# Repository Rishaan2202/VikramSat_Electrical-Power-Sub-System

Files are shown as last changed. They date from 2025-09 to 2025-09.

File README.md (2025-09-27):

# VikramSat.v0 EPS Journal!!!
<br>
<h3>Yooooo!!! It's me, Rishaan Sharma, a 14 year old Indian boy making a satellite with 4 of my teammates.
<br>
The Satellite is named as 'VikramSat'. It's a 2U CubeSat and yeah it's quite a cool project!
<br>
<br>
I have been assigned the duty to make a fully functional Electrical Power Sub-System (EPS) for the CubeSat.
<br>
<br>
So, I'm writing this journal which notifies about the progress regularly.
<br>
I hope you all will find this quite interesting. For more details do view JOURNAL.md in this repository containing the journal.</h3>
<br>
<br>
<h3>So, you might have gone throught JOURNAL.md, pretty interesting, right? Well, here is the Schematic of the EPS:-</h3>

<br>
<br>
<h3>Boom!!! It's Vampire Theme. I hope you like it. Here comes the PCB:-</h3>

<br>
<br>
<h3>Well, take a look at the 'Power Monster':-</h3>


<br>
<br>
<h3>You wanna see the BOM:-</h3>

<br>
<br>
<h3>Here's the Screenshot of the Cart for both LCSC and JLCPCB:-</h3>
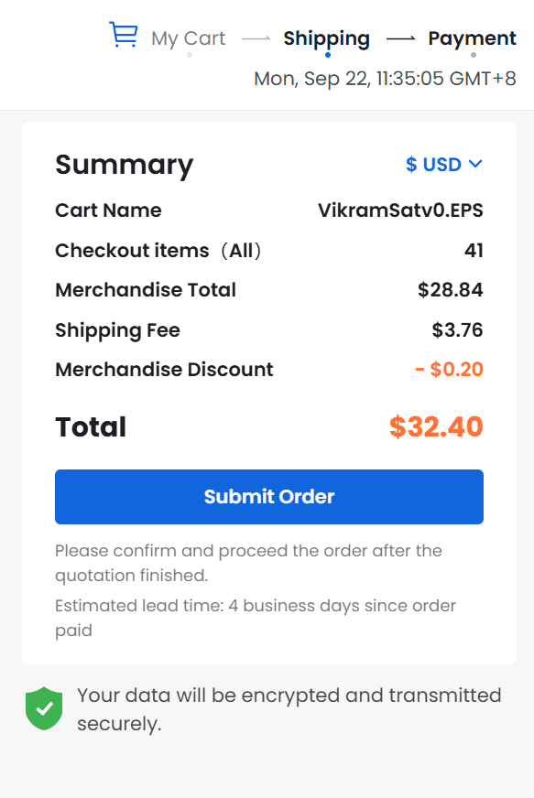
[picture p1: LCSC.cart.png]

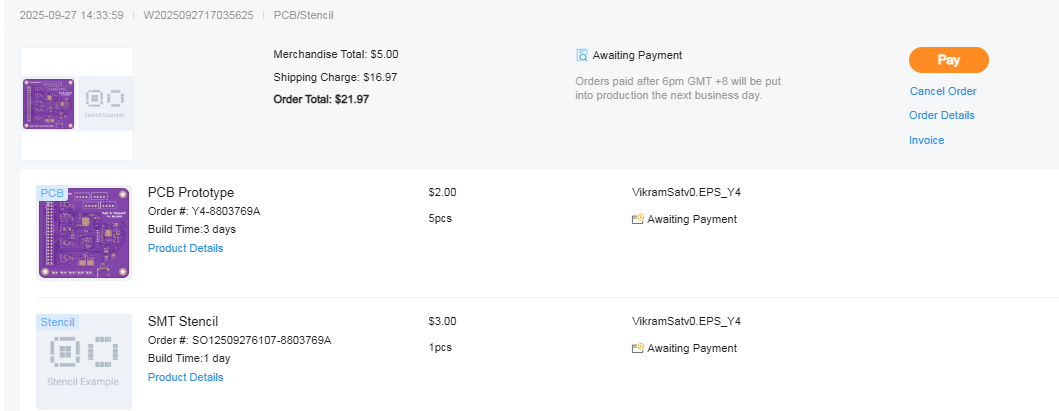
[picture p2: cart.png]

<br>
<h3>I hope you like them, well I couldn't do this better than that, cause I'm just a beginner!!!</h3>

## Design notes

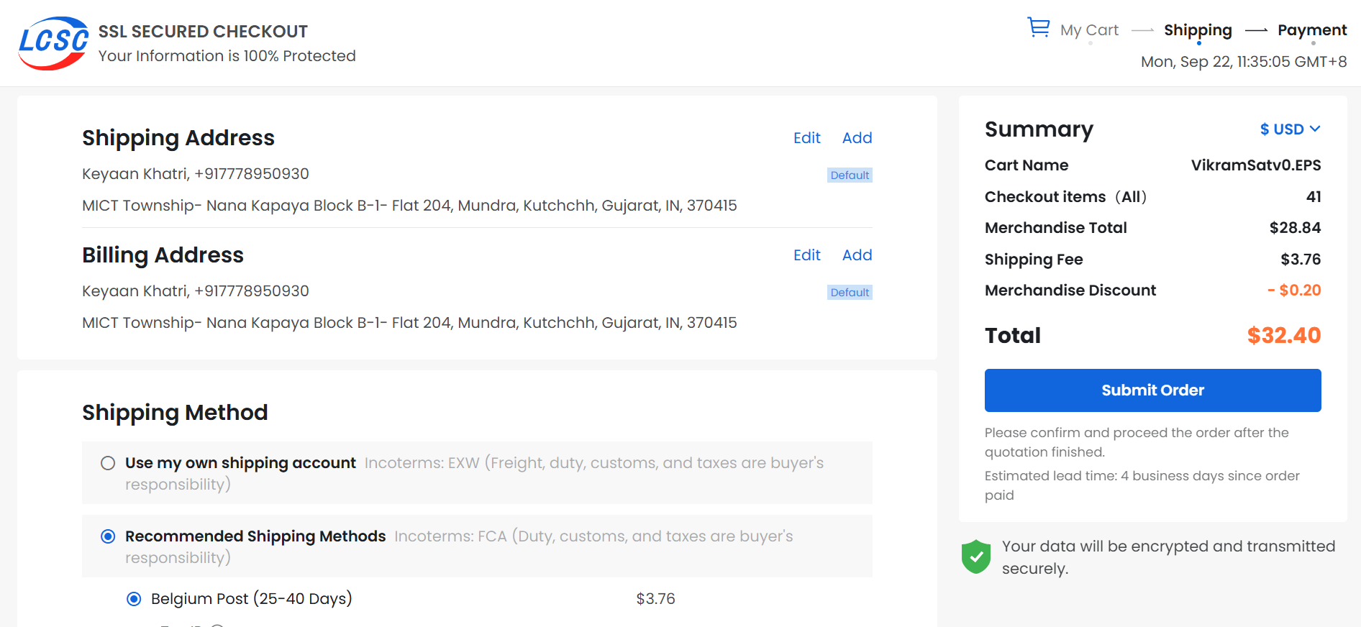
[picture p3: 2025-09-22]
Screenshot 2025-09-22 090605.png

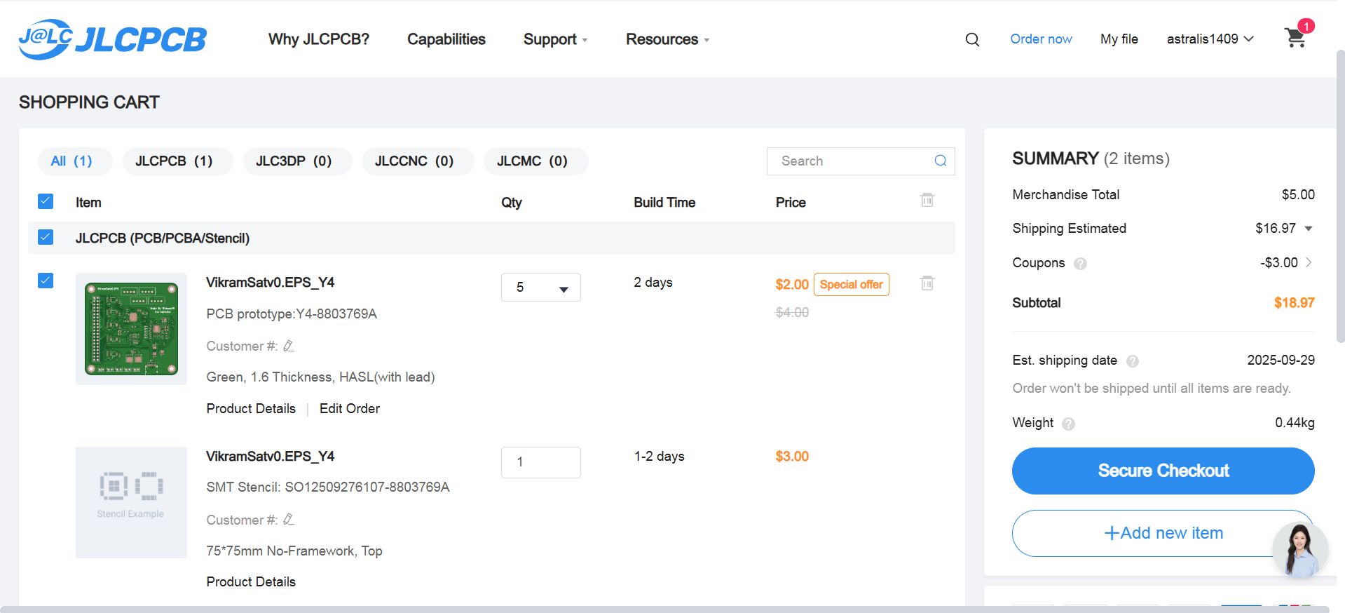
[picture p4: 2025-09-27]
Screenshot 2025-09-27 141404.png

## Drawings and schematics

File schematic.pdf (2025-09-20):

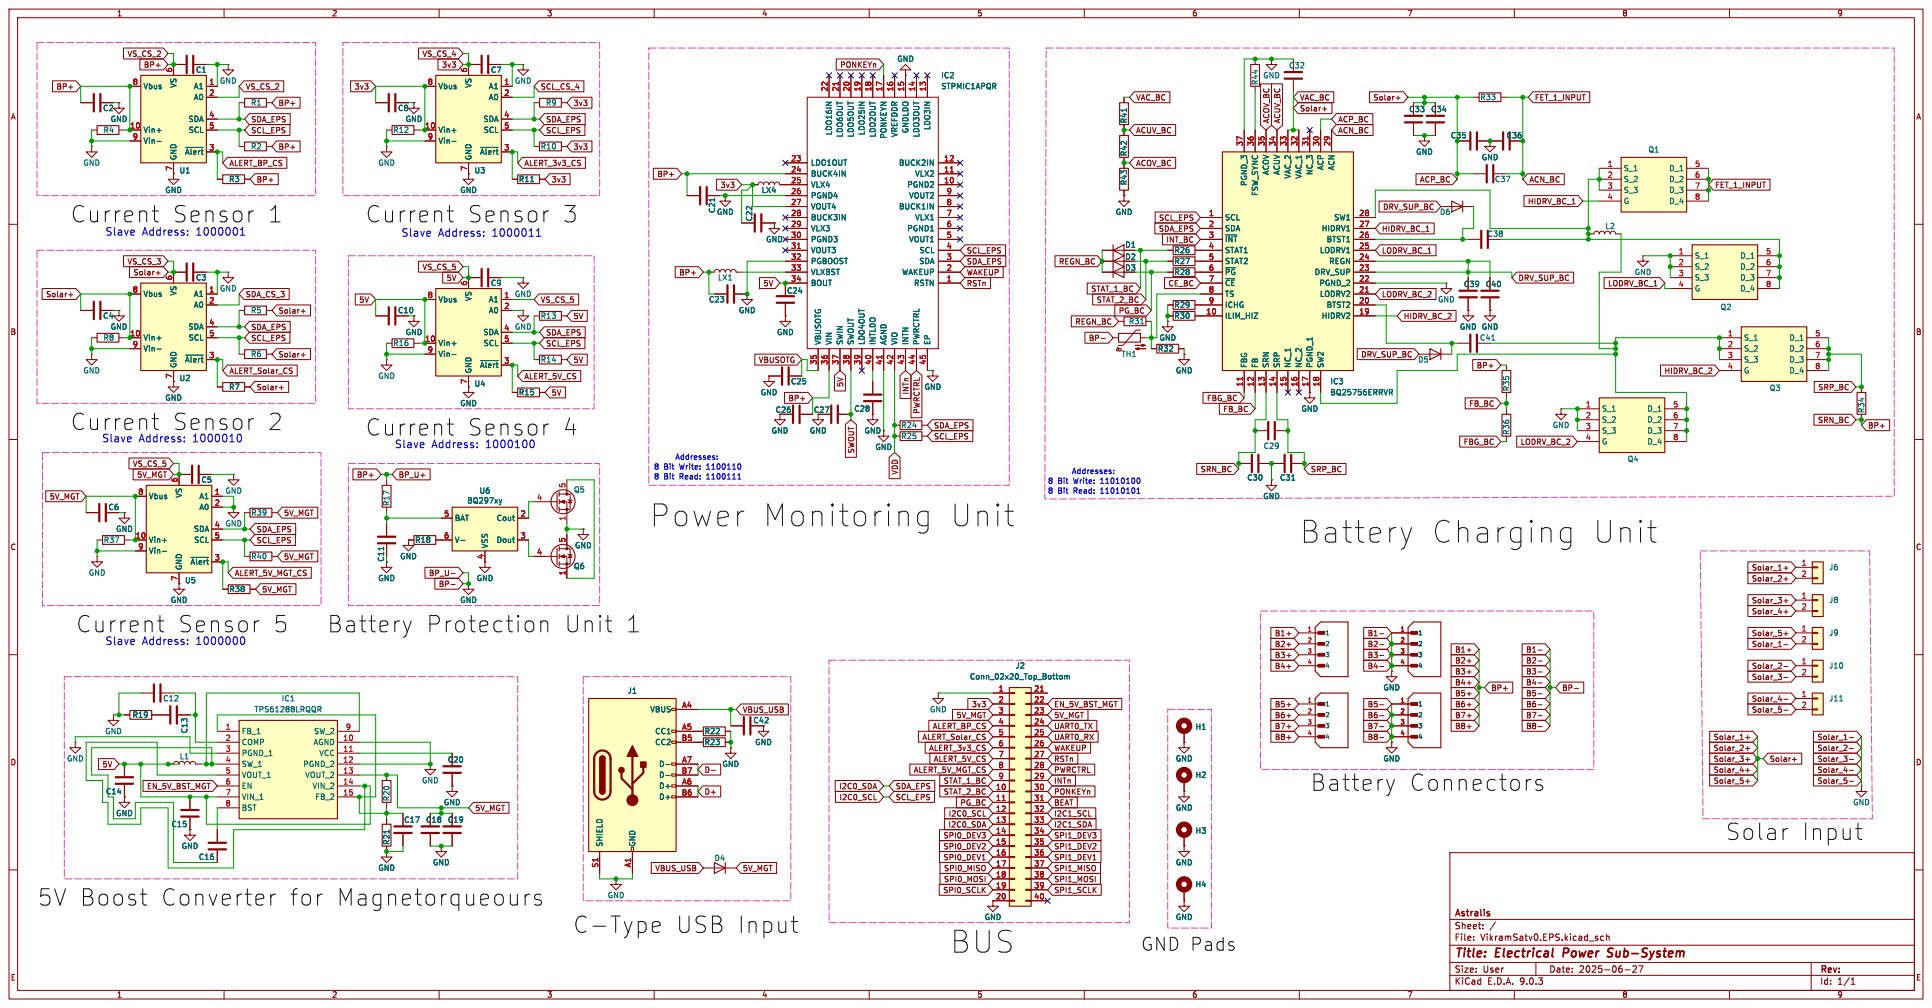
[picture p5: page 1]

7 A1 1 A0 2 SDA 4 SCL 5 ~{Alert}3 C1 GND

7 A1 1 A0 2 SDA 4 SCL 5 ~{Alert}3 U1 GND

7 A1 1 A0 2 SDA 4 SCL 5 ~{Alert}3 GND

7 A1 1 A0 2 SDA 4 SCL 5 ~{Alert}3 U4 C9 Vbus 8 Vin+ 10 Vin- 9 VS

7 A1 1 A0 2 SDA 4 SCL 5 ~{Alert}3 C9 U3 Vbus 8 Vin+ 10 Vin- 9 VS

7 A1 1 A0 2 SDA 4 SCL 5 ~{Alert}3 R7 GND

7 A1 1 A0 2 SDA 4 SCL 5 ~{Alert}3 U2 R39 GND

8 Q4 GND R36 R35 C41 D5 GND GND GND

7 A1 1 A0 2 SDA 4 SCL 5 ~{Alert}3 U5 GND

4 Cout 2 Dout 3 R18 U5 Vbus 8 Vin+ 10 Vin- 9 VS

5 1 GND GND GND GND C11 GND

5V Boost Converter for Magnetorqueours

Id: 1/1 Title: Electrical Power Sub-System

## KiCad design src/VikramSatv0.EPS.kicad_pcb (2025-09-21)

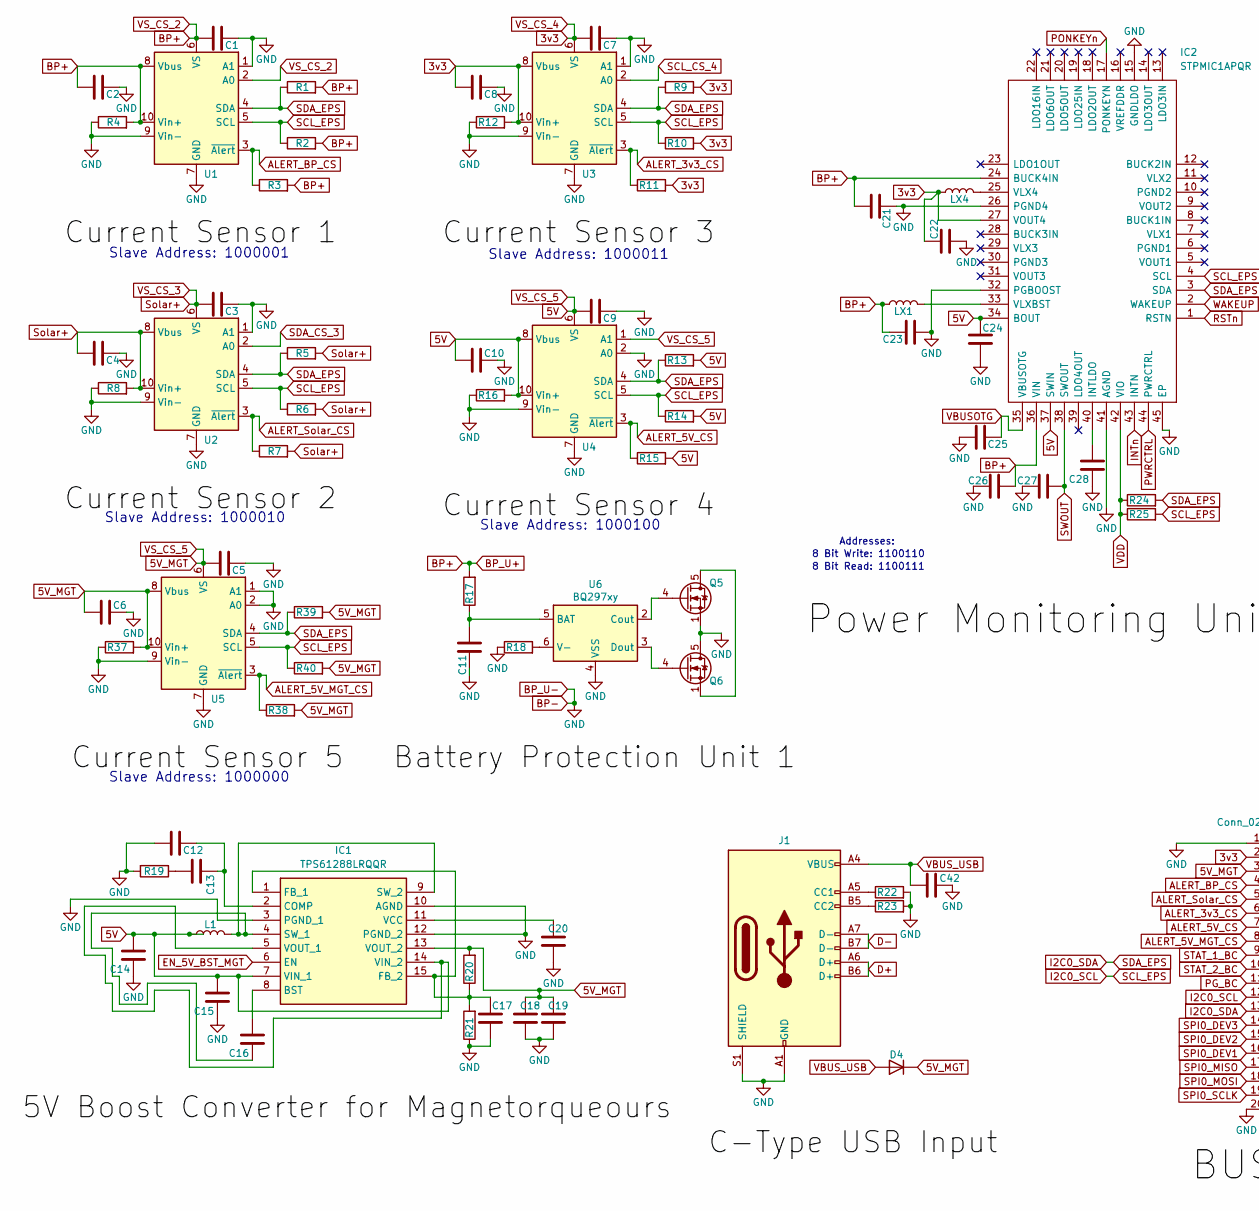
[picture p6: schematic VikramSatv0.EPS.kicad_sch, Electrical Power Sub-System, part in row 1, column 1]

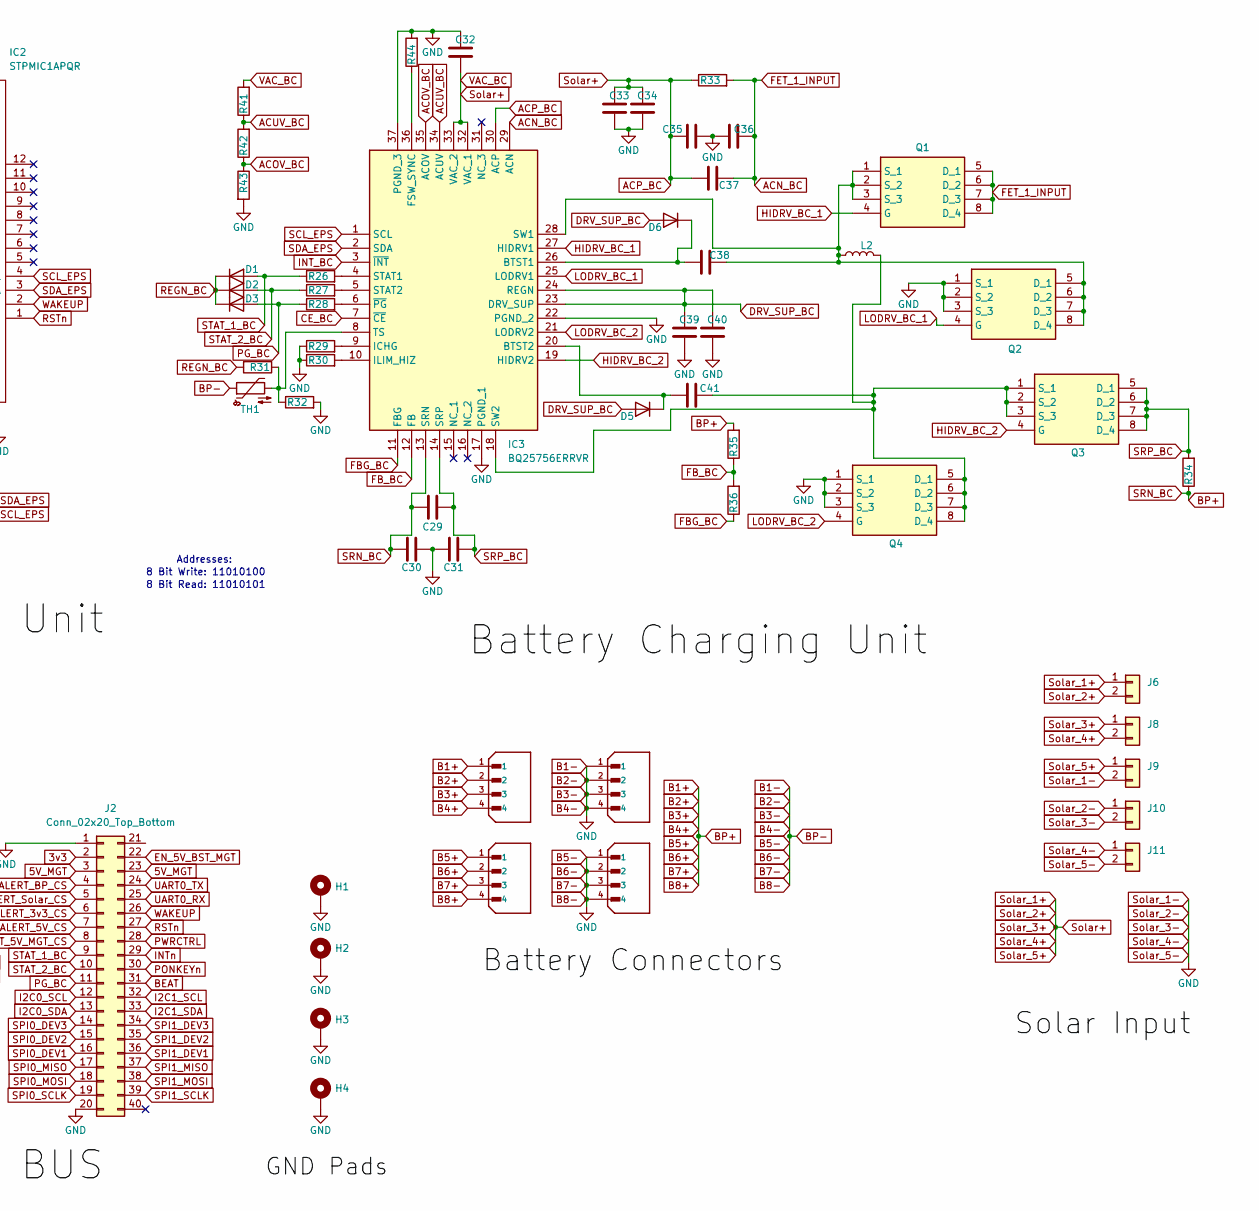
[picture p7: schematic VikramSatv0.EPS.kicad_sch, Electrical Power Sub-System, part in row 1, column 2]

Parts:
C1, C2, C3, C4, C5, C6, C7, C8, C9, C10, C11, C12, C15, C16, C17, C20, C29, C30, C31, C38, C41: 0.1uF; C_0402_1005Metric
C13: 1nF; C_0402_1005Metric
C14, C21, C22, C23, C24: 10uF; C_0805_2012Metric
C18, C19: 22uF; C_0402_1005Metric
C25, C26, C28, C39, C40: 4.7uF; C_0402_1005Metric
C27: 220uF; C_1206_3216Metric
C32, C42: 1uF; C_0402_1005Metric
C33, C34: 100uF; C_0805_2012Metric
C35, C36, C37: 470nF; C_0402_1005Metric
D1, D2, D3, D4, D5, D6: 1N4148WT; D_SOD-523
H1, H2, H3, H4: MountingHole_Pad; MountingHole_3mm_Pad_Via
IC1: TPS61288LRQQR; TPS61288; Mouser Part Number 595-TPS61288LRQQR
IC2: STPMIC1APQR; STPMIC1A; Mouser Part Number 511-STPMIC1APQR
IC3: BQ25756ERRVR; QFN50P500X600X100-37N-D; Mouser Part Number 595-BQ25756ERRVR
J1: USB_C_Receptacle_USB2.0_14P; USB_C_Receptacle_HRO_TYPE-C-31-M-12
J2: Conn_02x20_Top_Bottom; PinHeader_2x20_P2.54mm_Vertical
J3, J4, J5, J7: B4B-XH-A; JST_B4B-XH-A
J6, J8, J9, J10, J11: Conn_01x02; PinHeader_2x01_P2.54mm_Vertical
L1: 2.2uH; L_0402_1005Metric
L2: 10uH; L_0201_0603Metric
LX1, LX4: 1uH; L_0402_1005Metric
Q1, Q2, Q3, Q4: Mosfet 20A, 30V; Mouser Part Number 78-SISA14DN-T1-GE3
Q5, Q6: CSD16401Q5; TDSON-8-1
R1, R2, R5, R6, R9, R10, R13, R14, R24, R25, R39, R40: 4.7kΩ; R_0402_1005Metric
R3, R7, R11, R15, R22, R23, R26, R27, R28, R38: 10kΩ; R_0402_1005Metric
R4, R8, R12, R16, R37: 4mΩ; R_0402_1005Metric
R17: 330Ω; R_0402_1005Metric
R18: 2.2kΩ; R_0402_1005Metric
R19: 36.5kΩ; R_0402_1005Metric
R20: 105kΩ; R_0402_1005Metric
R21: 14.3kΩ; R_0402_1005Metric
R29: 4.22kΩ; R_0402_1005Metric
R30: 19.1kΩ; R_0402_1005Metric
R31: 5.23kΩ; R_0402_1005Metric
R32: 30.1kΩ; R_0402_1005Metric
R33: 1mΩ; R_0402_1005Metric
R34: 5mΩ; R_0402_1005Metric
R35: 174kΩ; R_0402_1005Metric
R36: 100kΩ; R_0402_1005Metric
R41: 357kΩ; R_0402_1005Metric
R42: 75kΩ; R_0402_1005Metric
R43: 22.6kΩ; R_0402_1005Metric
R44: 133kΩ; R_0402_1005Metric
TH1: 10kΩ NTC; R_0402_1005Metric
U1, U2, U3, U4, U5: INA226; VSSOP-10_3x3mm_P0.5mm
U6: BQ297xy; WSON-6_1.5x1.5mm_P0.5mm

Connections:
3v3: C7.2, C8.2, C22.1, IC2.27 (VOUT4), J2.2, LX4.1, R9.2, R10.2, R11.2, R12.2, U3.6 (VS), U3.8 (Vbus), U3.10 (Vin+)
5V: C5.2, C6.2, C9.2, C10.2, C14.2, C15.2, C18.2, C19.2, C24.1, D4.1 (K), IC1.5 (VOUT_1), IC1.7 (VIN_1), IC1.13 (VOUT_2), IC1.14 (VIN_2), IC2.34 (BOUT), IC2.37 (SWIN), J2.3, J2.23, L1.1, R13.2, R14.2, R15.2, R16.2, R20.2, R37.2, R38.2, R39.2, R40.2, U4.1 (A1), U4.6 (VS), U4.8 (Vbus), U4.10 (Vin+), U5.6 (VS), U5.8 (Vbus), U5.10 (Vin+)
ACN_BC: C36.2, C37.1, IC3.29 (ACN), Q1.5 (D_1), Q1.6 (D_2), Q1.7 (D_3), Q1.8 (D_4), R33.2
ACOV_BC: IC3.35 (ACOV), R42.1, R43.1
ACP_BC: C3.2, C4.2, C32.1, C33.2, C34.2, C35.1, C37.2, IC3.30 (ACP), IC3.32 (VAC_1), IC3.33 (VAC_2), J6.1, J6.2, J8.1, J8.2, J9.1, R5.2, R6.2, R7.2, R8.2, R33.1, R41.2, U2.6 (VS), U2.8 (Vbus), U2.10 (Vin+)
ACUV_BC: IC3.34 (ACUV), R41.1, R42.2
ALERT_3v3_CS: J2.6, R11.1, U3.3 (~Alert)
ALERT_5V_CS: J2.7, R15.1, U4.3 (~Alert)
ALERT_5V_MGT_CS: J2.8, R38.1, U5.3 (~Alert)
ALERT_BP_CS: J2.4, R3.1, U1.3 (~Alert)
ALERT_Solar_CS: J2.5, R7.1, U2.3 (~Alert)
B1+: C1.2, C2.2, C21.2, C23.1, C26.2, C29.1, C30.1, IC2.24 (BUCK4IN), IC2.36 (VIN), IC3.13 (SRN), J4.1, J4.2, J4.3, J4.4, J7.1, J7.2, J7.3, J7.4, LX1.1, R1.2, R2.2, R3.2, R4.2, R17.2, R34.1, R35.2, U1.2 (A0), U1.6 (VS), U1.8 (Vbus), U1.10 (Vin+)
B1-: C1.1, C2.1, C3.1, C4.1, C5.1, C6.1, C7.1, C8.1, C9.1, C10.1, C11.1, C12.2, C14.1, C15.1, C17.1, C18.1, C19.1, C20.1, C21.1, C22.2, C23.2, C24.2, C25.1, C26.1, C27.1, C28.1, C30.2, C31.1, C32.2, C33.1, C34.1, C35.2, C36.1, C39.1, C40.1, C42.2, H1.1, H2.1, H3.1, H4.1, IC1.3 (PGND_1), IC1.10 (AGND), IC1.12 (PGND_2), IC2.15 (GNDLDO), IC2.26 (PGND4), IC2.32 (PGBOOST), IC2.41 (AGND), IC2.45 (EP), IC3.17 (PGND_1), IC3.22 (PGND_2), IC3.37 (PGND_3), J1.A1 (GND), J1.A12 (GND), J1.B1 (GND), J1.B12 (GND), J1.S1 (SHIELD), J2.1, J2.20, J3.1, J3.2, J3.3, J3.4, J5.1, J5.2, J5.3, J5.4, J9.2, J10.1, J10.2, J11.1, J11.2, Q2.1 (S_1), Q2.2 (S_2), Q2.3 (S_3), Q4.1 (S_1), Q4.2 (S_2), Q4.3 (S_3), Q5.1 (S), Q5.2 (S), Q5.3 (S), Q6.5 (D), R4.1, R8.1, R12.1, R16.1, R18.1, R19.2, R21.1, R22.2, R23.2, R29.1, R30.1, R32.2, R37.1, R43.2, R44.2, TH1.1, U1.1 (A1), U1.7 (GND), U1.9 (Vin-), U2.1 (A1), U2.7 (GND), U2.9 (Vin-), U3.1 (A1), U3.7 (GND), U3.9 (Vin-), U4.2 (A0), U4.7 (GND), U4.9 (Vin-), U5.1 (A1), U5.2 (A0), U5.7 (GND), U5.9 (Vin-), U6.4 (VSS)
BEAT: J2.31
CE_BC: IC3.7 (~CE)
D+: J1.A6 (D+), J1.B6 (D+)
D-: J1.A7 (D-), J1.B7 (D-)
DRV_SUP_BC: C39.2, C40.2, D5.2 (A), D6.2 (A), IC3.23 (DRV_SUP), IC3.24 (REGN)
EN_5V_BST_MGT: IC1.6 (EN), J2.22
FBG_BC: IC3.11 (FBG), R36.1
FB_BC: IC3.12 (FB), R35.1, R36.2
HIDRV_BC_1: IC3.27 (HIDRV1), Q1.4 (G)
HIDRV_BC_2: IC3.19 (HIDRV2), Q3.4 (G)
I2C0_SCL: IC2.4 (SCL), IC3.1 (SCL), J2.12, R2.1, R6.1, R10.1, R14.1, R25.2, R40.1, U1.5 (SCL), U2.5 (SCL), U3.5 (SCL), U4.5 (SCL), U5.5 (SCL)
I2C0_SDA: IC2.3 (SDA), IC3.2 (SDA), J2.13, R1.1, R5.1, R9.1, R13.1, R24.2, R39.1, U1.4 (SDA), U2.4 (SDA), U3.4 (SDA), U4.4 (SDA), U5.4 (SDA)
I2C1_SCL: J2.32
I2C1_SDA: J2.33
INT_BC: IC3.3 (~INT)
INTn: IC2.43 (INTN), J2.29
LODRV_BC_1: IC3.25 (LODRV1), Q2.4 (G)
LODRV_BC_2: IC3.21 (LODRV2), Q4.4 (G)
unnamed: C13.2, R19.1
unnamed: C41.1, D5.1 (K), IC3.20 (BTST2)
unnamed: C38.1, D6.1 (K), IC3.26 (BTST1)
unnamed: C16.2, IC1.8 (BST)
unnamed: C12.1, C13.1, IC1.2 (COMP)
unnamed: C17.2, IC1.1 (FB_1), IC1.15 (FB_2), R20.1, R21.2
unnamed: C16.1, IC1.4 (SW_1), IC1.9 (SW_2), L1.2
unnamed: C20.2, IC1.11 (VCC)
unnamed: C28.2, IC2.40 (INTLDO)
unnamed: IC2.25 (VLX4), LX4.2
unnamed: IC2.33 (VLXBST), LX1.2
unnamed: IC3.36 (FSW_SYNC), R44.1
unnamed: IC3.9 (ICHG), R29.2
unnamed: IC3.10 (ILIM_HIZ), R30.2
unnamed: IC3.4 (STAT1), R26.2
unnamed: IC3.5 (STAT2), R27.2
unnamed: C38.2, IC3.28 (SW1), L2.1, Q1.1 (S_1), Q1.2 (S_2), Q1.3 (S_3), Q2.5 (D_1), Q2.6 (D_2), Q2.7 (D_3), Q2.8 (D_4)
unnamed: C41.2, IC3.18 (SW2), L2.2, Q3.1 (S_1), Q3.2 (S_2), Q3.3 (S_3), Q4.5 (D_1), Q4.6 (D_2), Q4.7 (D_3), Q4.8 (D_4)
unnamed: IC3.8 (TS), R31.1, R32.1, TH1.2
unnamed: IC3.6 (~PG), R28.2
unnamed: J1.A5 (CC1), R22.1
unnamed: J1.B5 (CC2), R23.1
unnamed: Q5.5 (D), Q6.1 (S), Q6.2 (S), Q6.3 (S)
unnamed: Q5.4 (G), U6.2 (Cout)
unnamed: Q6.4 (G), U6.3 (Dout)
unnamed: C11.2, R17.1, U6.5 (BAT)
unnamed: R18.2, U6.6 (V-)
PG_BC: D3.2 (A), J2.11, R28.1
PONKEYn: IC2.17 (PONKEYN), J2.30
PWRCTRL: IC2.44 (PWRCTRL), J2.28
REGN_BC: D1.1 (K), D2.1 (K), D3.1 (K), R31.2
RSTn: IC2.1 (RSTN), J2.27
SCL_CS_4: U3.2 (A0)
SDA_CS_3: U2.2 (A0)
SPI0_DEV1: J2.16
SPI0_DEV2: J2.15
SPI0_DEV3: J2.14
SPI0_MISO: J2.17
SPI0_MOSI: J2.18
SPI0_SCLK: J2.19
SPI1_DEV1: J2.36
SPI1_DEV2: J2.35
SPI1_DEV3: J2.34
SPI1_MISO: J2.37
SPI1_MOSI: J2.38
SPI1_SCLK: J2.39
SRP_BC: C29.2, C31.2, IC3.14 (SRP), Q3.5 (D_1), Q3.6 (D_2), Q3.7 (D_3), Q3.8 (D_4), R34.2
STAT_1_BC: D1.2 (A), J2.9, R26.1
STAT_2_BC: D2.2 (A), J2.10, R27.1
SWOUT: C27.2, IC2.38 (SWOUT)
UART0_RX: J2.25
UART0_TX: J2.24
VBUSOTG: C25.2, IC2.35 (VBUSOTG)
VBUS_USB: C42.1, D4.2 (A), J1.A4 (VBUS), J1.A9 (VBUS), J1.B4 (VBUS), J1.B9 (VBUS)
VDD: IC2.42 (VIO), R24.1, R25.1
WAKEUP: IC2.2 (WAKEUP), J2.26

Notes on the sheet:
8 Bit Write: 11010100
8 Bit Read: 1100111
8 Bit Read: 11010101
Slave Address: 1000010
Slave Address: 1000001
Slave Address: 1000000
Slave Address: 1000011
8 Bit Write: 1100110
Addresses:
Slave Address: 1000100

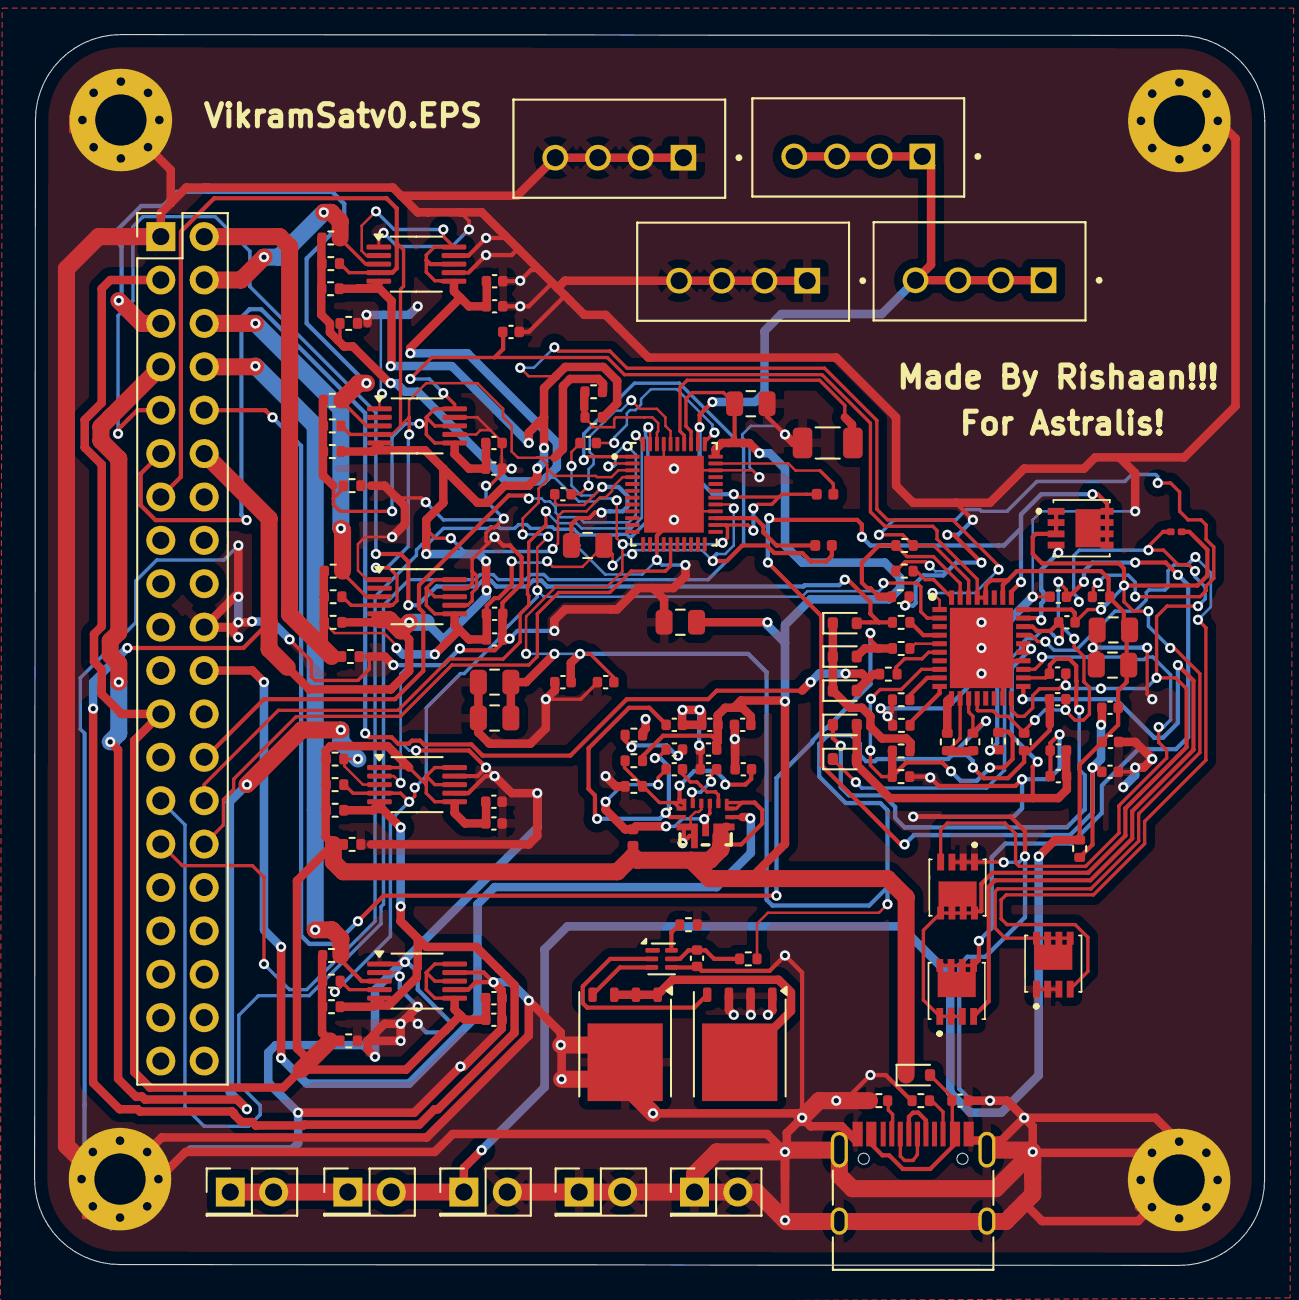
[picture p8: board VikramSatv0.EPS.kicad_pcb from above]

Board: 2 copper layers, 72.0 x 72.0 mm, 127 parts (0 on the bottom side), 66 nets.

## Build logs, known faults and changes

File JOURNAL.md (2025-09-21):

---
title: "VikramSAT EPS Board"
author: "@Rishaan"
description: "Electrical Power Sub-System for VikramSAT"
created_at: "2025-07-01"
---

# July 1, 2025, Getting Started!!!
I guess all the necessary information about this repository was available on README.md but whatever, there should not be laziness just for the introduction again, so here it is. I am Rishaan Sharma, aged 14, working on the VikranSat.v0 with 4 of my friendzzz. I have been assigned the responsibility to make the Electrical Power Sub-System of the CubeSat. Yup it is a big duty, but I am up to it with all my patience and hardwork. I have made the whole EPS PCB Schematic 3 times in the past, and yes, It's me building it again for the fourth time due to some technical glitches. I will Keep you updated each time I do something. That's all for today, we'll meet again very soon!!!
<br>
<h2> Time Invested: 0 Hours <h2/>

# July 3, 2025, Day-2!
Yoo, what's goin' on?, not that uch progress today, most of the time invested in learning, "how to use Kikad?", but I did choose some components, take a look at them:-
<br>
<br>

<h2>Time Invested: ~1.5 Hours</h2>

# July 4, 2025, Day-3!
Yuppp, I'm up again! Everything going kinda chaotic here, just because of tight schedule, only a bit work done today. Just take a look at it:-
<br>
<br>

<h2>Time Invested: ~0.75 Hours</h2>

# July 5, 2025, Day-4!
Yeah, it's the day-4 and still a bit work done. But as compared to previous days, it's more ig. Here, take a look:-
<br>
<br>

<h2>Time Invested: ~0.75 Hours</h2>

# July 11, 2025, Day-5!
Huhhh, that was a week full of tiring examinations. By the way, did a little work today. Here, see it:-
<br>
<br>

<h2>Time Invested: ~1.25 Hours</h2>

# July 12, 2025, Day-6!
Yooo, I completed the battery chargers today!!!. It was very tiring. See this:-
<br>
<br>

<h2>Time Invested: 3 Hours</h2>

# July 13, 2025, Day-7!
Yeahhhh!, I'm back with something interesting. I finalised the 3.3V buck converter for the load. Also did some meeting kinda stuff with the project head and we finalised to have RP2350A as the power management IC. Negligible work done on the schematic today. Nevermind, just take a look:-
<br>
<br>

<h2>Time Invested: 2 Hours</h2>

# July 14, 2025, Day-8!
What's up, I'm back with something interesting. Well, it was a very chaotic day for me and I could only invest a bit time for this. that's the completion ofthe 3.3V Buck Converter. It was quite interesting and easy. Take this:-
<br>
<br>

<h2>Time Invested: 0.75 Hours</h2>

# July 15, 2025, Day-9!
Yoooo!!! Today I kinda wasted my time just to add this RP2350A PMIC to my schematic, cause I'm just 14 and struggling to find my way in this electrc world. Whatever, just see this:-
<br>
<br>

<h2>Time Invested: ~1.5 Hours</h2>

# July 17, 2025, Day-10!
Hello there!!! I'm back with the start to add the Type-C port on the PCB and kinda wasted the time to know how to do it, yet no efficient outcome. well see it:-
<br>
<br>

<h2>Time Invested: ~1.5 Hours</h2>

# July 19, 2025, Day-11!
Yeah, It's me again!!! Today I made the Battery Protection unit. Well that's just a BMS kinda IC, but I like exagerrating names, so yeah, see this:-
<br>
<br>

<h2>Time Invested: ~0.5 Hours</h2>

# July 20, 2025, Day-12!
How're you all!!! I am here today with the completion of the C-Type Receptacle on the schematic. Well, we haven't figured out anything about the PMIC(RP2350A), as we have to change it because of it's power consumption. Well, here's the schematic of the day:-
<br>
<br>

<h2>Time Invested: ~0.5 Hours</h2>

# July 23, 2025, Day-13!
I'm back with only a bit things done today. Well I was guided to add LICENSE and README.md in this repository. I also had a meeting with my teammates to figure out if there was something wrong with the power board, and fortunately, there wasn't any flaw, just the values of some components were not fixed as I was not able to figure them out, but hopefully I guess they will be fixed after a few tutorials. Well, I also did very minor changes to the C-Type receptacle today. There's nothing to see in it, but just see it:-
<br>
<br>

<h2>Time Invested: ~1.75 Hours</h2>

# July 24, 2025, Day-13!
I'm back today with a good news that I found a very nice Power Management IC which is STPMIC1A, for the EPS. I also did all the connections of the current sensors. The schematic looks like a monster now, take a look:-
<br>
<br>

<h2>Time Invested: ~2.25 Hours</h2>

# July 26, 2025, Day-14!
Hello again!!! I am back with something really exciting. I did the connections of PMIC and the configuration has been changed from 4P1S*2 to 8P1S! A few ICs have also been reduced such as one battery charging IC with its protectin unit. It was a drastic change and a lot of effor for me today, but here's the outcome:-
<br>
<br>

<h2>Time Invested: ~2 Hours</h2>

# July 27, 2025, Day-15!
Yeahhh!!! I kinda selected the 5V boost converter for the Magnetorqueours. You might be wondering why I am having a separate boost converter for the Magnetorqueours, that's because of low current and high voltage output from the PMIC which could only be tolerated by other 5V load except the Magnetorqueours. I have built it partially, I'll do it properly tomorrow, so here's the converter/regulator:-
<br>
<br>

<h2>Time Invested: ~0.75Hours</h2>

# July 28, 2025, Day-16!
Helloooo again!!! negligible work done today. I just read some articles about the basics of Li-Ion battery chargers to select another battery charger, cause I am not able to understand, interpret and implement the values of a few components exactly for the specific application of ours, and I don't wanna take even a bit of risk. Well no image for today.
<h2>Time Invested: ~0.5Hours</h2>

# July 29, 2025, Day-17!
OMG!!! Finally!!! I completed the schematic for the EPS, just footprints of some components are left to be added. See this thing:-
<br>
<br>

<h2>Time Invested: ~3.75Hours</h2>

# July 30, 2025, Day-18!
Yooo!!! I am finally gonna finish the schematic! Just a few values of components is left. I also added the bus. Take a look:-
<br>
<br>

<h2>Time Invested: ~3.25Hours</h2>

# July 31, 2025, Day-19!
It is a very hard and rigid work for me to build the EPS of VikramSATv0. I worked many hours for the completion of this project under the given time for the submission of Undercity, but I failed to do so. I am very dissapointed to say that I was not able to complete the EPS and now it is 31st of July (Last date for the submission of project).Heyyy, why is this becoming sad? Don't you know that another program is gonna come? Here are the images of the work done today:- 
<br>
<br>


<h2>Time Invested: ~5.5Hours</h2>

# August 1, 2025, Day-20!
Hello!!! What did you think? That I would leave journaling? I'm not that kind of guy dude! I never give up! Well, I mentioned about a program yesterday. And that's gonna be #grounded. I came to know that projects made on KiCAD are eligible for the participation in #grounded, so I'll continue journaling till I finish the EPS of VikramSATv0 and gonna submit it for the PCBA grant. Here is the image for the work done today:-
<br>
<br>

<h2>Time Invested: ~2.75Hours</h2>

# August 3, 2025, Day-21!
Yooo!!! I segregated and position all the units of the EPS, but joining them with traces is left. Here's the PCB till now:-
<br>
<br>

<h2>Time Invested: ~3 Hours</h2>

# August 5, 2025, Day-22!
Yeahhh!!! just did the creation of my project in Groundplane. You might be wondering why it consumed so much time? Well, that's because of the irritating error popping up on my screen after I clicked on the button for the submission of the project. The screenshot was also not being uploaded properly. After a few restarts, it miraclously worked and got submitted. I also hit the exit button on my browser before hitting the commit changes button, so yeah I typed this all for today again, I also changed the theme of my schematic editor to 'The Vampire Theme', pretty cool huh? Well see it yourself (and yeah the dashboard of Groundplane too!):-
<br>
<br>


<h2>Time Invested: ~1.5 Hours</h2>

# August 7, 2025, Day-23!
Huhhh! I saw a tutorial, did some more traces and yeah, that's all I did today except changing the PCB editor's theme (It looks so cool!). Take a look at the progress:-
<br>
<br>

<h2>Time Invested: ~1 Hours</h2>

# August 9, 2025, Day-24!
Okayyy, It's just like I did a bit routing today, but found some repeated routings which was done at 90° by me. The main thing is that I am not able to delete it!!! It may be because of some kinda glitch or something. You know what it means. Restart!!! Huhhh:-
<br>
<br>

<h2>Time Invested: ~1.25 Hours</h2>

# August 10, 2025, Day-25!
Nahhh!!! I can't find any way to delete a single trace individually. I saw tutorials too, but no outcome. Now I'm gonna leave a complaint or issue kinda thing on GitLab. No image for today, Sorry guysss!!!
<h2>Time Invested: ~0.25 Hours</h2>

# August 12, 2025, Day-26!
Still not able to fix the problem!!! I also was not able to get any help from GitLab. I also tried to reinstall KiCad. But, that also wasn't helpful. Well I tried to do a little bit of logo editing today. Look at it:-
<br>
<br>

<h2>Time Invested: ~1.75 Hours</h2>

# August 14, 2025, Day-27!
Yeahhh!!! Problem solved! I got the answer from KiCad Forum. The issue was that I didn't allow the selections of tracks from the bottom right corner. I did a few connections, but the connection of Battery Charging Unit was completely a mess!!! See it:-
<br>
<br>

<h2>Time Invested: ~1.75 Hours</h2>

# August 15, 2025, Day-28!
Happy Independence Day!!! So, today is India's Independence day. The atmosphere is filled with nationalism all around. Today I did most of the traces. Only a few remaining. Take a look at the PCB:-
<br>
<br>

<h2>Time Invested: ~1.5 Hours</h2>

# August 16, 2025, Day-29!
Yeah!!! Most of the traces are done, only Grounds and a few traces (Which I was not able to route) are left. I'll do them later. Take a look at this bad boyyy:-
<br>
<br>

<h2>Time Invested: -1 Hours</h2>

# August 18, 2025, Day-30!
Sooo!!! all the rest of traces done except the Common ground. The board looks nice now. I kinda love my hardwork (who doesn't?) Take a look at the PCB:-
<br>
<br>

<h2>Time Invested: ~0.75 Hours</h2>

# August 21, 2025, Day-31!
Yooo!!! I added a GND plane in my project today and also researched a lot about the battery connectors which I was not able to finalise, so I'll do that later:-
<br>
<br>

<h2>Time Invested: ~1 Hours</h2>

# August 23, 2025, Day-32!
Yeah!!! A few more 'Grounds' done! I was not able to connect the components and also don't know that are they being connected or ot just by adding a 'through via'. I also researched about the connectors a bit, but I wasn't able to find the footprint, so I left that work for another time. And yeah, that's it for today, but don't forget to see 'The Progress':- 
<br>
<br>

<h2>Time Invested: ~1 Hours</h2>

# August 25, 2025, Day-33!
Sameeee!!! today also the same thing! I can now only see GNDs all around me, cause I'm kinda 'grounded', yeah, and that's what I am working for. Now, only a few ratlines remain. So here's today's image:- 
<br>
<br>

<h2>Time Invested: ~1 Hours</h2>

# August 25, 2025, Day-33!
I did more connections today!!! Now only 10-15 ratlines are left to be 'traced'. I'm very excited to do this last thing!!! Well take a look at the progress:- 
<br>
<br>

<h2>Time Invested: ~0.75 Hours</h2>

# August 25, 2025, Day-33!
Yoooo!!! Only 3 ratlines left!!! I am not able to connect these pins. It's kinda >95% IMPOSSIBLE. But, I'll do it. You just see this:- 
<br>
<br>

<h2>Time Invested: ~1.25 Hours</h2>

# September 1, 2025, Day-34!
Yayyy!!! All the traces done! but there are many DRC errors (Sad Emoji* 3)! I'll do it (maybe I'll be able to do it). So see the 3D thing now. It looks cool, but the borders are also a bit deformed. Huhhh, I'll fix that too:- 
<br>
<br>

<h2>Time Invested: ~1 Hours</h2>

# September 5, 2025, Day-35!
There's a bad newzzz!!! I tried to fix the borders, but I came to know the the borders which I drew earlier were longer!!! Now I have to review a few connections again to ensure that they fit in the PCB! Here's the image, you can review the progress:- 
<br>
<br>

<h2>Time Invested: ~0.75 Hours</h2>

# September 7, 2025, Day-36!
Uhmmm!!! I don't think that I would like to write anything, cause the image would tell it all!! (Sad Emoji*3). 181 errors, seriously?:-
<br>
<br>

<h2>Time Invested: ~0.75 Hours</h2>

# September 9, 2025, Day-37!
Seriouslyyy!!! Can you just see what that is? IG Digikey or mouser gave me wrong footprints! How to FIX it!!!!!:-
<br>
<br>

<h2>Time Invested: ~1 Hours</h2>

# September 13, 2025, Day-38!
Yeah, there's progress. I fixed that 'pad problem', but IDK how the border got deleted!!! Huhhh!:-
<br>
<br>

<h2>Time Invested: ~2 Hours</h2>

# September 15, 2025, Day-39!
Just a few 'Warnings' corrected today. Nothin' much:-
<h2>Time Invested: ~1.5 Hours</h2>

# September 16, 2025, Day-40!
Ohhh! Silly me!, the borders weren't deleted, they were just hidden. I am gonna ignore the errors of the FETs, cause the pads intersect, but I saw the datasheet, and found that they are intentionally sorted. So IG the PCB will be completed in 2 or 3 days. Take a look at the 3D view. It's kinda "WOW, did I really made it?":-
<br>
<br>

<h2>Time Invested: ~1.15 Hours</h2>

# September 17, 2025, Day-41!
I, I did it!!!!!! I made the PCB! It's so cool that I made my first PCB! Here, see the final view, well the 3D model for many aren't there.:-
<br>
<br>

<h2>Time Invested: ~1.75 Hours</h2>

# September 18, 2025, Day-42!
I did a few formalities for the grant in my repo today. Well, there is more to do. I also talked with my teammates regarding this and did the file work which were just lying in my Laptop.
<br>
<br>
<h2>Time Invested: ~2.15 Hours</h2>

# September 19, 2025, Day-43!
Nothing much today, just a bit of thickening of traces!
<br>
<br>
<h2>Time Invested: ~0.75 Hours</h2>

# September 20, 2025, Day-44!
This is it! Success! It is the first time I felt like I did something big. I submitted the EPS!!!:-
<br>
<br>

<h2>Time Invested: ~3.15 Hours</h2>

# September 21, 2025, Day-44!
Actually!!! I submitted the wrong ss of the cart which showed total $33.77, but now when I added LCSC too, it has rose too $50+ as you might see in the README.md. I have mailed Zach Latta Sir for a change in the registration information!:-
<br>
<br>
<h2>Time Invested: ~3.5 Hours</h2>

<h1>Total Days Spent = 44
<br>
Total Hours Spent = 81.5</h1>
